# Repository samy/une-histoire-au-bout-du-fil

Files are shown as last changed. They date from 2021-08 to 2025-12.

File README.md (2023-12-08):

# Une histoire au bout du fil

Ce projet a pour objectif principal de convertir de vieux téléphones en boîte à histoires ou livres d'or!
<table width="100%" align="center">
    <tr>
      <td width="33%" valign="top" align="center"><a href="https://github.com/samy/une-histoire-au-bout-du-fil/tree/main/Boite_a_histoires/README.md"><strong>Boîte à histoires</strong><br />
        </a>
      </td>
      <td width="33%" valign="top" align="center"><a href="https://github.com/samy/une-histoire-au-bout-du-fil/tree/main/Livre_dor/README.md"><strong>Livre d'or</strong><br /></a></td>
  </tr>
</table>

Pour me contacter : samy@rabih.fr

# Licence
<br />Ce projet est partagé sous la licence <a rel="license" href="https://creativecommons.org/licenses/by-nc-sa/4.0/deed.fr">Attribution - Pas d’Utilisation Commerciale - Partage dans les Mêmes Conditions 4.0 International</a>.

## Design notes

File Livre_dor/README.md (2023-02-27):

## Notes
- Pour récupérer le son injecté dans le jack 3.5mm, on peut se brancher sur les PINs L et R (ceux sous le connecteur jack justement, R et GND sont reliés)

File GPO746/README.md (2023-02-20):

# GPO 746

Ce téléphone provient de Grande-Bretagne (et cet exemplaire date de 1968)


## Adaptation au boitier générique "Une histoire au bout du fil"

Afin de simplifier la conversion de mes téléphones, j'avais créé un boitier générique, avec 4 connecteurs A, B, C et D reliés aux 4 fils du cadran.
Mais cela fonctionnait avec un cadran français, et pas britannique comme celui-ci (le code couleur est différent).

| PIN PCB | Couleur fil UK |
| --- | --- |
| A | Bleu  |
| B | Orange  |
| C | Brun clair (ou rose)  |
| D | Gris  |

## Détection décrochage
Il faudra se brancher sur les connecteurs T1 et T19 du circuit du téléphone (et à défaut, sur T1 et T4)

## Pieds
La hauteur sous l'appareil étant insuffisante pour glisser le lecteur de carte microSD, il est nécessaire d'imprimer des cylindres de **16mm** de diamètre et d'au moins **6mm** de haut.

## Combiné
Un bruit de fond peut survenir dans le combiné, il suffit de rajouter une résistance de 4.7kΩ (pour un volume de 10). Si nécessaire monter jusqu'à 10kΩ (pour un volume de 15).

## Lecteur microSD
Si la SD n'est pas reconnue (erreur Time Out du DFPlayer), enlever (à la pince) la résistance située dans le lecteur SD

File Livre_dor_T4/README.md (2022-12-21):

## Notes
- Pour récupérer le son injecté dans le jack 3.5mm, on peut se brancher sur les PINs L et R (ceux sous le connecter jack justement, R et GND sont reliés)

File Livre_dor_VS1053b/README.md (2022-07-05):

## Correspondance des pins XIAO - VS1053

| VS1053 | XIAO |
| --- | --- |
| CS  | D7  |
| MISO  | D9  |
| (MO)SI  | D10  |
| SCK | D8  |
| XCS | D6  |
| XRESET | D5  |
| XDCS | D4  |
| DREQ | D3  |

Seul l'emplacement des MISO, MOSI et SCK est réellement important (pour les autres il vous suffit de changer les valeurs dans le code).
Correction dans la bibliothèque Adafruit VS1053

#define VS1053_CONTROL_SPI_SETTING                                             \
  SPISettings(2000000, MSBFIRST, SPI_MODE0) //!< VS1053 SPI control settings
#define VS1053_DATA_SPI_SETTING                                                \
  SPISettings(12000000, MSBFIRST, SPI_MODE0) //!< VS1053 SPI data settings
  
A rajouter dans le code Arduino:

#define SPI_HAS_TRANSACTION 1

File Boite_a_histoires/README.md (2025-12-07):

# Boite à histoires "Socotel U43"

Ce modèle date de 1943 (d'où son nom).

WhatsApp Image 2022-01-11 at 14 30 25 (1)

*Photo par [Lulu La Lucette](https://lululalucette.com)*

# Pré-requis
Sur la carte micro-SD ou la clé USB, créez un dossier nommé *MP3* et stockez-y vos fichiers à faire jouer par le téléphone.
Ils doivent être prefixés par un numéro à 4 chiffres, qui les fera correspondre au chiffre composé sur le cadran : 0001.mp3 ou 0001 - cequevousvoulez.mp3 pour le morceau 1, etc)

# Utilisation
Il vous suffit de décrocher le combiné, de composer un ou plusieurs chiffres et d'écouter l'histoire qui vous est racontée.

# Principe de fonctionnement
On reprend ici la logique du modèle S63 https://github.com/samy/une-histoire-au-bout-du-fil/blob/main/Boite_a_histoires_S63/README.md

Le boitier électronique associé à ce projet vient se brancher sur la connectique existante du téléphone, pour se relier à trois éléments déja présents:
- la détection du décrochage
- le combiné (et son haut-parleur)
- et surtout le cadran rotatif

Deux différences majeures par rapport à la version S63:
- le boitier a du être réduit en hauteur, l'espace disponible étant plus réduit
- afin d'éviter d'être parasité par le circuit du téléphone, on rajoute ici un sucre "maison" pour relier le cadran et l'Arduino

Il est désormais possible de composer des numéros entrre 1 et 4 chiffres !

# Schéma du circuit

<p>
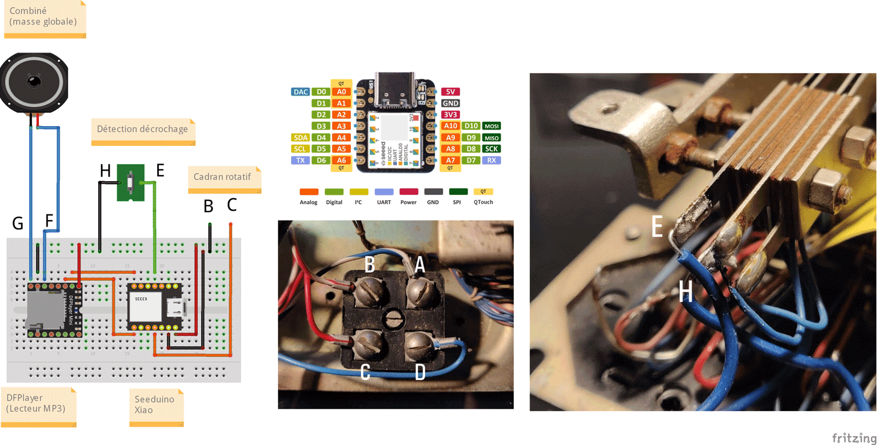
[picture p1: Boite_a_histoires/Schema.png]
  
</p>

Comme mon précédent modèle de téléphone, on utilise ici un DFPlayer, mais combiné cette fois à un [Seeeduino Xiao](https://wiki.seeedstudio.com/Seeeduino-XIAO/) qui a l'avantage d'être extrèmement compact (sans pour autant sacrifier les performances).

La seule particularité ici est que le décrochage n'a pu être géré directement par les bornes situées sous l'appareil : en effet, comme pour le cadran, les parasites liés au circuit sont trop importants. J'ai donc du directement me brancher sur les contacts du système électromécanique qui s'enclenche quand on raccroche.

# Gestion du volume (optionnelle)
Celle-ci peut s'activer via la constante VOLUME_HANDLING dans le code.
Il vous suffit ensuite de cabler un potentiomètre en reprenant la convention suivante:

potentiometre

# Compatibilité avec d'autres cadrans
Si vous avez un autre modèle qu'un Socotel S63 ou un U43, les cablâges sont sans doute tout de même similaires à l'image ci-dessous. Seuls les cables rouge et blanc-rouge sont utiles dans notre cas.



# Licence
<br />Ce projet est partagé sous la licence <a rel="license" href="https://creativecommons.org/licenses/by-nc-sa/4.0/deed.fr">Attribution - Pas d’Utilisation Commerciale - Partage dans les Mêmes Conditions 4.0 International</a>.

# Ressources:
- Autre projet, réalisé par [comeetie](https://github.com/comeetie/), qui utilise un U43, mais directement avec un Raspberry Pi: [https://github.com/comeetie/Monvieuxtelephone/](https://github.com/comeetie/Monvieuxtelephone/) (et qui ajoute pas mal de fonctionnalités: météo, horaires de passage du RER, etc)
- Source d'inspiration: [Le projet S63 de Revolunet](https://github.com/revolunet/s63)

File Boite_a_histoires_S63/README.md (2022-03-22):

# Boite à histoires "Socotel S63"



(source : [x0r.fr](https://x0r.fr/blog/53) )

## Schema du circuit


<table border="0" cellspacing="0" cellpadding="0">
  <tr>
    <td width="50%"></td>
    <td></td>
  </tr>
</table>

## Liaison cadran - Arduino

| Couleur | Destination |
| --- | --- |
| Blanc-bleu | Port A |
| Blanc-rouge | Port B |
| Rouge | Port C |
| Bleu | Port D |

# Matériel à rassembler
- Un [Arduino Nano](https://www.gotronic.fr/art-carte-arduino-nano-12422.htm) (mais vous pouvez utiliser d'autres modèles sans problème, selon votre boitier)
- Un [DFPlayer Mini](https://www.gotronic.fr/art-module-mp3-dfr0299-22404.htm)
- Une résistance de 1kΩ

# Pré-requis avant utilisation
Sur la carte micro-SD, créez un dossier nommé _MP3_ et stockez-y vos fichiers à faire jouer par le téléphone. Ils doivent être prefixés par un numéro à 4 chiffres, qui les fera correspondre au chiffre composé sur le cadran :
- **0001.mp3** ou **0001 - cequevousvoulez.mp3** pour le morceau 1,
- **0002.mp3** ou **0002 - cequevousvoulez.mp3** pour le morceau 2,
- etc

# Code Arduino
On utilise ici deux bibliothèques non natives :
- [*DFRobotDFPlayerMini*](https://github.com/DFRobot/DFRobotDFPlayerMini) (installable via le gestionnaire de bibliothèques)
- [*RotaryDial*](https://github.com/markfickett/Rotary-Dial), (téléchargeable sur Github et installable au format ZIP)

Le [code source](./Boite_a_histoires_S63.ino) est abondamment commenté en français.

# Etiquette du cadran
Celle-ci est constituée d'un disque de 51mm de diamètre, et la police utilisée semble être du Univers Condensed Medium avec en 7.5pt un crénage de 46 (merci à [Jean-François Porchez](https://typofonderie.com) pour la suggestion de la police Univers)



# Licence
<br />Ce projet est partagé sous la licence <a rel="license" href="https://creativecommons.org/licenses/by-nc-sa/4.0/deed.fr">Attribution - Pas d’Utilisation Commerciale - Partage dans les Mêmes Conditions 4.0 International</a>.

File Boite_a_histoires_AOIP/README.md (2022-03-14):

# Une histoire au bout du fil

Ce projet a pour objectif principal de convertir ce vieux téléphone (de la marque AOIP) en boîte à histoires!
telephone

# Technologie

L'idée principale qui sous-tend ce projet est de ne pas dénaturer le téléphone d'origine : on réutilisera donc la circuiterie d'origine, qui est en bon état.

Comme beaucoup de projets embarqués c'est ici un Arduino (Nano) qui sera employé.

Qui dit histoires dit "son" : en effet, on va devoir jouer des fichiers audio à travers le combiné (d'origine).

Cette tâche va être confiée à un lecteur [DFPlayer Mini](https://wiki.dfrobot.com/DFPlayer_Mini_SKU_DFR0299) (de la marque DFRobot)

En résumé vous aurez besoin de:
- Arduino Nano (officiel ou non)
- un DFPlayer Mini (autour de 5€)
- une carte micro-SD
- câbles Dupont ou de fils électriques classiques
- une [breadboard](https://www.robot-maker.com/ouvrages/2-1-utiliser-breadboard/) (carte de prototypage) pour pouvoir brancher les composants et les fils et facilement les replacer
- *ou* une [version à souder](https://www.amazon.fr/prototypage-Breadboard-Protoboard-Prototype-%C3%A9lectroniques/dp/B08F2TB5Y5/)

# Licence
<br />Ce projet est partagé sous la licence <a rel="license" href="https://creativecommons.org/licenses/by-nc-sa/4.0/deed.fr">Attribution - Pas d’Utilisation Commerciale - Partage dans les Mêmes Conditions 4.0 International</a>.

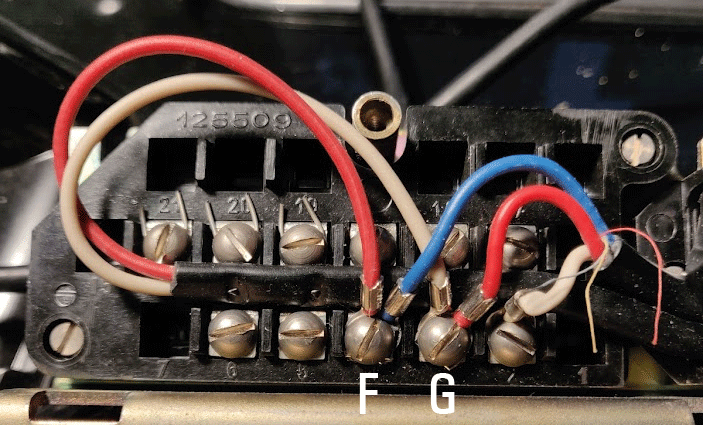
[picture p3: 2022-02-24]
Boite_a_histoires/Ressources/Platine_basse.png

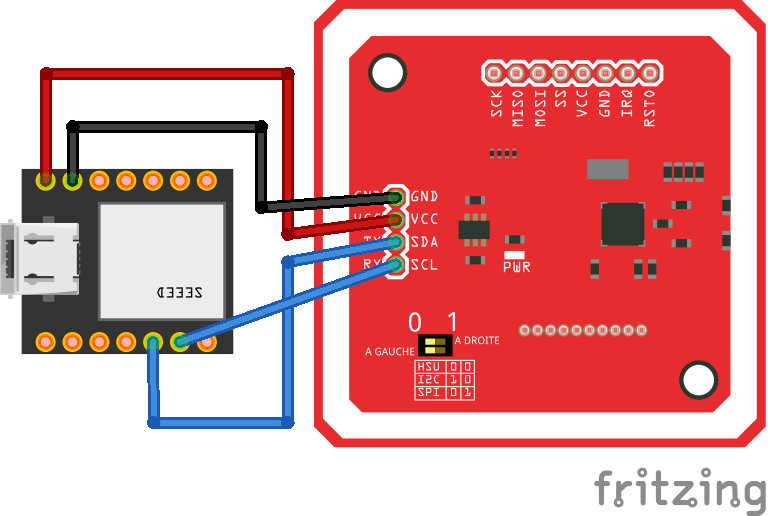
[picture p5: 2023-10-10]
Stethoscope/PN532.png

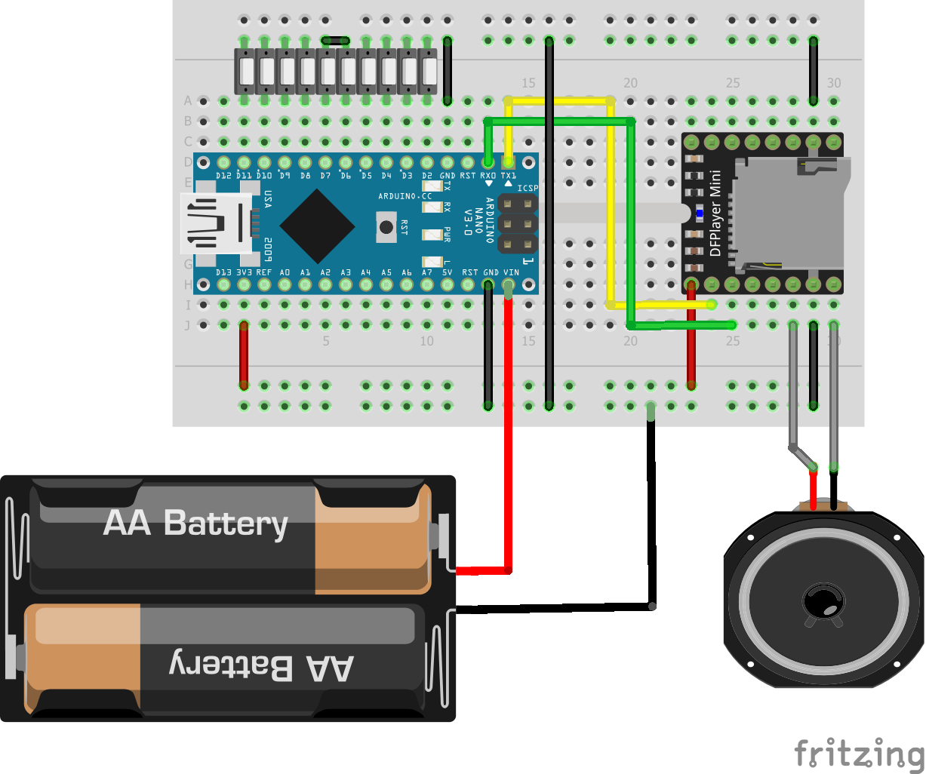
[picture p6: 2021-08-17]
Boite_a_histoires_AOIP/Schema.png

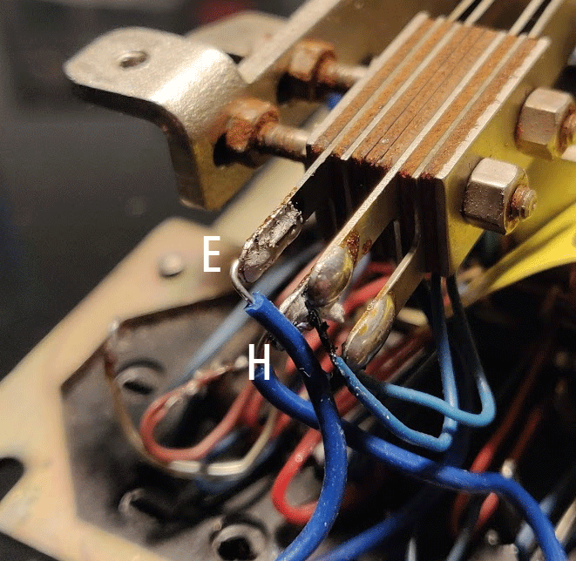
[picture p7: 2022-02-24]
Boite_a_histoires/Ressources/Contacts_decrochage.png

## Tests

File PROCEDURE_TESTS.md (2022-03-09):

# Procédure de tests
Celle-ci est commune à tous les modèles

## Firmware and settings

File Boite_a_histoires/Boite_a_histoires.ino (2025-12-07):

/* Bibliothèques requises */
#include <Bounce2.h>
#include "RotaryDial2.h"
#include <Keypad_MC17.h>
#include <Wire.h>
#include <Keypad.h>
#include "DFRobotDFPlayerMini.h" /* Lecteur MP3 */
#include <LibPrintf.h>


// Fonctionnalités
#define INTRO_ENABLE false /* Pour activer le message au décrochage  */
#define INTRO_DELTA 1      /* Temps minimal en secondes entre deux diffusions du message de décrochage */

#define DIALER_ENABLE true               /* Pour activer le clavier */
#define DIAL_RANDOM false                  /* Si le cadran doit lire au hasard */
#define DIALER_TYPE DIALER_TYPE_ROTARY    /* Type : DIALER_TYPE_KEYPAD clavier à touches, DIALER_TYPE_ROTARY cadran rotatif */
#define DIALER_COUNTRY "FR"               /* FR pour cadrans français, UK pour britanniques */
#define DIALED_NUMBERS_MAX 1              /* Nombre maximal de numéros (1 : 10 chiffres, 2 : 100 chiffres, etc) */
#define STORAGE_DEVICE DFPLAYER_DEVICE_SD /* Support de stockage: DFPLAYER_DEVICE_SD pour SD, DFPLAYER_DEVICE_U_DISK pour clé USB */
#define LED_ENABLE false                  /* Activation de la LED d'indication de fonctionnement */
#define LED_PIN D9                        /* Gestion de la LED */
#define USE_BOUNCE_INSTEAD_OF_DIRECT 0    /* Pour des systèmes de raccrochage un peu sensibles */

#define KEYPAD_REVERSED_MATRIX true

#define RANDOM_PLAY_ON_HANG false              /* Activation du mode Lecture automatique et aléatoire au décrochage de l'appareil */
#define RANDOM_PLAY_ON_HANG_START_ON_TRACK -1 /* En mode aléatoire, le numéro du morceau joué au démarrage */
#define USE_SOFTWARE_RANDOM false             /* Lecture aléatoire en se basant sur le nombre de fichiers, dans le cas ou randomAll() marche mal */


#define VOLUME_HANDLING false /* Activation de la molette de volume branchée sur le PIN A1 */
#define MAX_VOLUME 10         /* Volume maximal quand la molette est au maximum */

#define HANG_REVERSE true /* Inversion du raccrochage, selon les appareils */

// Gestion bouton supplémentaire
#define EXTRA_HANG false        /* Activation du bouton secondaire pour le raccrochage */
#define EXTRA_HANG_PIN A2       /* PIN du bouton supplémentaire de raccrochage */
#define EXTRA_HANG_REVERSE true /* Si le fonctionnement de ce bouton supplémentaire est inversé */

// Inclusion des valeurs par défaut pour celles qui n'ont pas été personnalisées ci-dessus
#include "Variables.h"

Keypad_MC17 keypad(makeKeymap(keys), rowPins, colPins, ROWS, COLS, I2CADDR);

// "Bouton" utilisé pour gérer le décrochage
Bounce2::Button button = Bounce2::Button();

void setup() {
  delay(3000);

  pinMode(PIN_HANG, INPUT_PULLUP);
  button.attach(PIN_HANG, INPUT_PULLUP);
  button.interval(5);
  button.setPressedState(HANG_REVERSE ? 1 : 0);

  /* Optionnel: Gestion du volume */
  if (VOLUME_HANDLING) {
    pinMode(A1, INPUT);
  }

  /* Optionnel: LED d'indication de fonctionnement */
  if (LED_ENABLE) {
    pinMode(LED_PIN, OUTPUT);
    digitalWrite(LED_PIN, HIGH);
  }

  /* Optionnel: 2e dispositif de raccrochage */
  if (EXTRA_HANG) {
    pinMode(EXTRA_HANG_PIN, INPUT_PULLUP);
  }

  /* Connexion série pour la remontée d'informations au PC */
  Serial.begin(9600);

  /* Connexion série pour la communication avec le DFPlayer */
  mySoftwareSerial.begin(9600);

  /* Gestion du clavier */
  if (DIALER_ENABLE) {
    /* Clavier à touches */
    if (DIALER_TYPE == DIALER_TYPE_KEYPAD) {
      Wire.begin();  // now needed
      keypad.begin();
    } else {
      /* Cadran rotatif */
      RotaryDial2::setup(PIN_PULSE, DIALED_NUMBERS_MAX);
    }
  }

  /* Connexion au DFPlayer */
  if (!myDFPlayer.begin(mySoftwareSerial, true, true)) {  //Use softwareSerial to communicate with mp3.
    Serial.println("bad");
    return;
  }
  Serial.println("Starting successfully");

  myDFPlayer.outputDevice(STORAGE_DEVICE);
  myDFPlayer.pause();

  delay(3000);
  audioFilesCount = myDFPlayer.readFileCounts(DFPLAYER_DEVICE_SD);
  Serial.print("Audio files count");
  Serial.println(audioFilesCount);
  myDFPlayer.volume(20);
  printSettingsToConsole();
}

void loop() {
  /* Optionnel: Actualisation du volume */
  if (VOLUME_HANDLING) {
    int volume = getVolume();

    if (lastVolume == -1 || abs(lastVolume - volume) > 30) {
      lastVolume = volume;

      Serial.println(map(volume, 0, 1023, 0, MAX_VOLUME));
      delay(200);
      myDFPlayer.volume(map(volume, 0, 1023, 0, MAX_VOLUME));
      delay(100);
    }
  }
  if (myDFPlayer.available()) {
    printDetail(myDFPlayer.readType(), myDFPlayer.read());  //Print the detail message from DFPlayer to handle different errors and states.
  }
  button.update();



  /* Si le téléphone est raccroché, on stoppe la lecture du MP3 (il n'a pas de véritable stop() et on passe à l'itération suivante */
  if (isHangedUp() || (EXTRA_HANG && isExtraHangedUp())) {

    Serial.println("Offline");
    delay(200);
    if (phoneStatus != 0) {
      myDFPlayer.pause();
    }

    phoneStatus = 0;
    dialedIndex = 0;
    return;
  } else {
    if (phoneStatus == 0) {
      myDFPlayer.available();

      delay(300);
      /* Si l'option de lecture aléatoire au décrochage est activée, on joue un audio au hasard
      le changement de phoneStatus évite qu'il soit joué plusieurs fois */
      if (RANDOM_PLAY_ON_HANG) {
        if (RANDOM_PLAY_ON_HANG_START_ON_TRACK != -1) {
          Serial.print("Play on start: track ");
          Serial.println(RANDOM_PLAY_ON_HANG_START_ON_TRACK);
          myDFPlayer.play(RANDOM_PLAY_ON_HANG_START_ON_TRACK);
        } else {
          if (!USE_SOFTWARE_RANDOM) {
            Serial.println("Random play on start");

            myDFPlayer.randomAll();
          } else {
            int randomFileNumber = random(1, audioFilesCount);
            Serial.print("Random play (software) on start:");
            Serial.println(randomFileNumber);

            myDFPlayer.play(randomFileNumber);
          }
        }
      } else {
        Serial.println("No random");
      }
      dialedIndex = 0;
      phoneStatus = 1;
    }
  }

  if (timeSinceLastIntroPlay == 99999 || (phoneStatus == 1 && needToPlayIntro())) {
    Serial.println("needToPlayIntro?");
    phoneStatus = 2;
    playIntro();
  }
  phoneStatus = 2;
  if (DIALER_ENABLE) {
    if (DIALER_TYPE == DIALER_TYPE_KEYPAD) {
      char key = keypad.getKey();
      if (key) {
        numberDialed = convertKeypadToInt(key);
      }
    } else {
      /* Si un numéro a été composé sur le téléphone, on le stocke */
      if (strcmp(DIALER_COUNTRY, "FR") == 0) {
        if (RotaryDial2::available()) {

          delay(200);

          numberDialed = RotaryDial2::read();
        }
      }
      if (strcmp(DIALER_COUNTRY, "UK") == 0) {
        numberDialed = getUkRotaryDialerNumber();
      }
    }

    /* Si un numéro a été composé, alors on joue le MP3 correspondant */
    if (numberDialed != -1) {
      dialedIndex++;

      /* Stockage des numéros composés */
      if (dialedIndex <= DIALED_NUMBERS_MAX) {
        dialedNumbers[dialedIndex - 1] = numberDialed;
        numberDialed = -1;
        if (dialedIndex < DIALED_NUMBERS_MAX) {
          return;
        }
      }
      if (dialedIndex > DIALED_NUMBERS_MAX) {
        dialedIndex = 0;
        numberDialed = -1;
        return;
      }
      for (int i = 0; i < dialedIndex; i++) {
        finalDialedNumber += pow(10, DIALED_NUMBERS_MAX - 1 - i) * dialedNumbers[i];
        dialedNumbers[i] = 0;
      }
      dialedIndex = 0;
      myDFPlayer.pause();
      if (DIAL_RANDOM) {
        finalDialedNumber = random(1, audioFilesCount + 1);
        myDFPlayer.available();
        delay(300);
        Serial.print("randomDialedNumber=");
        Serial.println(finalDialedNumber);
        myDFPlayer.randomAll();
      } else {
        Serial.print("finalDialedNumber=");
        Serial.println(finalDialedNumber);
        myDFPlayer.playMp3Folder(finalDialedNumber);
      }

      numberDialed = -1;
      finalDialedNumber = 0;
      return;
    }
  } else {
    /* Si le lecteur n'est pas actuellement en train de jouer */
    if (myDFPlayer.readState() == 514 || myDFPlayer.readState() == 512) {
      delay(1000);

      myDFPlayer.randomAll();
    }
    delay(1000);
  }
}

/* Récupération de l'état de décroché/raccroché */
bool isHangedUp() {
  if (USE_BOUNCE_INSTEAD_OF_DIRECT) {
    return button.pressed();
  }
  return (HANG_REVERSE ? 0 : 1) == digitalRead(PIN_HANG);
}
/* Récupération de l'état de décroché/raccroché */
bool isExtraHangedUp() {
  return (EXTRA_HANG_REVERSE ? 0 : 1) == digitalRead(EXTRA_HANG_PIN);
}

/* Détermination de la nécessité de jouer le message d'intro */
bool needToPlayIntro() {
  if (!INTRO_ENABLE) {
    return false;
  }
  /* Si l'écart entre le compteur de temps actuel et la dernière lecture de l'introduction dépasse l'intervalle qu'on a configuré,
    et que le téléphone était décroché avant
    on joue l'intro */
  if (timeSinceLastIntroPlay == 0 || (millis() - timeSinceLastIntroPlay) > INTRO_DELTA * 1000) {
    return true;
  }
  return false;
}

/* Diffusion du message d'introduction */
void playIntro() {
  timeSinceLastIntroPlay = millis();

  delay(1000);                 /* On laisse aux utilisateurs le temps de décrocher */
  myDFPlayer.playMp3Folder(0); /* L'intro est stockée dans le fichier commençant par 0000 dans le dossier MP3 */
}

int getUkRotaryDialerNumber() {
  int reading = digitalRead(PIN_PULSE);
  int numberDialed = -1;
  if ((millis() - lastStateChangeTime) > dialHasFinishedRotatingAfterMs) {
    if (needToPrint) {
      // if it's only just finished being dialed, we need to send the number down the serial
      // line and reset the count. We mod the count by 10 because '0' will send 10 pulses.
      numberDialed = count % 10;
      needToPrint = 0;
      count = 0;
      cleared = 0;
    }
  }

  if (reading != lastState) {
    lastStateChangeTime = millis();
  }
  if ((millis() - lastStateChangeTime) > debounceDelay) {
    // debounce - this happens once it's stablized
    if (reading != trueState) {
      // this means that the switch has either just gone from closed->open or vice versa.
      trueState = reading;
      if (trueState == HIGH) {
        // increment the count of pulses if it's gone high.
        count++;
        needToPrint = 1;  // we'll need to print this number (once the dial has finished rotating)
      }
    }
  }
  lastState = reading;
  return numberDialed;
}

long getVolume() {
  return analogRead(A1);
}
int convertKeypadToInt(char key) {
  return key - '0';
}

void printDetail(uint8_t type, int value) {
  switch (type) {
    case TimeOut:
      Serial.println(F("Time Out!"));
      break;
    case WrongStack:
      Serial.println(F("Stack Wrong!"));
      break;
    case DFPlayerCardInserted:
      Serial.println(F("Card Inserted!"));
      break;
    case DFPlayerCardRemoved:
      Serial.println(F("Card Removed!"));
      break;
    case DFPlayerCardOnline:
      Serial.println(F("Card Online!"));
      break;
    case DFPlayerPlayFinished:
      Serial.print(F("Number:"));
      Serial.print(value);
      Serial.println(F(" Play Finished!"));
      break;
    case DFPlayerError:
      Serial.print(F("DFPlayerError:"));
      switch (value) {
        case Busy:
          Serial.println(F("Card not found"));
          break;
        case Sleeping:
          Serial.println(F("Sleeping"));
          break;
        case SerialWrongStack:
          Serial.println(F("Get Wrong Stack"));
          break;
        case CheckSumNotMatch:
          Serial.println(F("Check Sum Not Match"));
          break;
        case FileIndexOut:
          Serial.println(F("File Index Out of Bound"));
          break;
        case FileMismatch:
          Serial.println(F("Cannot Find File"));
          break;
        case Advertise:
          Serial.println(F("In Advertise"));
          break;
        default:
          break;
      }
      break;
    default:
      break;
  }
}

const char* boolToEnabled(int value) {
  return value ? "enabled" : "disabled";
}

void printSettingsToConsole() {
  Serial.println();
  Serial.println("# Settings summary");
  printf("* Intro : %s\n", boolToEnabled(INTRO_ENABLE));
  if (INTRO_ENABLE) {
    printf("  * Delay after intro plays a new time : %d seconds\n", INTRO_DELTA);
  }
  printf("* Reversed hang : %s\n", boolToEnabled(HANG_REVERSE));

  printf("* Dialer : %s\n", boolToEnabled(DIALER_ENABLE));
  if (DIALER_ENABLE) {
    if (DIAL_RANDOM) {
      printf("  * Random mode: %s\n", boolToEnabled(DIAL_RANDOM));
    } else {
      printf("  * Max numbers: %d\n", int(pow(10, DIALED_NUMBERS_MAX)));
    }
    printf("  * Type: %s\n", DIALER_TYPE);
    if (DIALER_TYPE == DIALER_TYPE_KEYPAD) {
      printf("  * Matrix reversed: %s\n", boolToEnabled(KEYPAD_REVERSED_MATRIX));
    }
    printf("  * Country: %s\n", DIALER_COUNTRY);
  }
  printf("* Storage type : %s\n", STORAGE_DEVICE == DFPLAYER_DEVICE_U_DISK ? "USB" : "SD");
  printf("* LED : %s\n", boolToEnabled(LED_ENABLE));
  if (LED_ENABLE) {
    printf("  * LED pin: %s\n", LED_PIN);
  }
  printf("* Volume handling : %s\n", boolToEnabled(VOLUME_HANDLING));
  if (VOLUME_HANDLING) {
    printf("  * Max volume: %d\n", MAX_VOLUME);
  }
  printf("* Use software random : %s\n", boolToEnabled(USE_SOFTWARE_RANDOM));
  printf("* Random play on hang : %s\n", boolToEnabled(RANDOM_PLAY_ON_HANG));
  if (RANDOM_PLAY_ON_HANG && -1 != RANDOM_PLAY_ON_HANG_START_ON_TRACK) {
    printf("  * First track on hang: %d\n", RANDOM_PLAY_ON_HANG_START_ON_TRACK);
  }
  if (EXTRA_HANG) {
    printf("* Use extra hang switch : %s\n", boolToEnabled(EXTRA_HANG));
    printf("  * Pin: %s\n", EXTRA_HANG_PIN);
    printf("  * Reversed: %s\n", boolToEnabled(EXTRA_HANG_REVERSE));
  }

  //Extra settings
  if (USE_BOUNCE_INSTEAD_OF_DIRECT) {
    printf("* Use bounce instead of direct switch handling : %s\n", boolToEnabled(USE_BOUNCE_INSTEAD_OF_DIRECT));
  }


  Serial.println();
}

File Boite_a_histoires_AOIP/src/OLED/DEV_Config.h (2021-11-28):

/******************************************************************************
**************************Hardware interface layer*****************************
  | file      	:	DEV_Config.h
  |	version		:	V1.0
  | date		:	2017-12-11
  | function	:
	Provide the hardware underlying interface
******************************************************************************/
#ifndef _DEV_CONFIG_H_
#define _DEV_CONFIG_H_

#include <SPI.h>
#include <Wire.h>

#define USE_SPI_4W 1
#define USE_IIC    0

#define IIC_CMD        0X00
#define IIC_RAM        0X40
/****************************************************************************************
		//Use the  library function definition
*****************************************************************************************/
//GPIO config
//OLED
#define OLED_CS A3
#define OLED_DC A2
#define OLED_CS_0	    digitalWrite(OLED_CS, LOW)
#define OLED_CS_1		digitalWrite(OLED_CS, HIGH)

#ifndef OLED_RST
#define OLED_RST 8
#endif
#define OLED_RST_0		digitalWrite(OLED_RST, LOW)
#define OLED_RST_1		digitalWrite(OLED_RST, HIGH)


#define OLED_DC_0		digitalWrite(OLED_DC, LOW)
#define OLED_DC_1	  	digitalWrite(OLED_DC, HIGH)

#define SPIRAM_CS 5
#define SPIRAM_CS_0     digitalWrite(SPIRAM_CS, LOW)
#define SPIRAM_CS_1     digitalWrite(SPIRAM_CS, HIGH)

/*------------------------------------------------------------------------------------------------------*/
uint8_t System_Init(void);

void SPI4W_Write_Byte(uint8_t DATA);
uint8_t SPI4W_Read_Byte(uint8_t DATA);

void I2C_Write_Byte(uint8_t value, uint8_t Cmd);

void Driver_Delay_ms(unsigned long xms);
void Driver_Delay_us(int xus);

#endif

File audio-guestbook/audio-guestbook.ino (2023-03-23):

/**
 * Audio Guestbook, Copyright (c) 2022 Playful Technology
 * 
 * Tested using a Teensy 4.0 with Teensy Audio Shield, although should work 
 * with minor modifications on other similar hardware
 * 
 * When handset is lifted, a pre-recorded greeting message is played, followed by a tone.
 * Then, recording starts, and continues until the handset is replaced.
 * Playback button allows all messages currently saved on SD card through earpiece 
 * 
 * Files are saved on SD card as 44.1kHz, 16-bit, mono signed integer RAW audio format 
 * --> changed this to WAV recording, DD4WH 2022_07_31
 * 
 * 
 * Frank DD4WH, August 1st 2022 
 * for a DBP 611 telephone (closed contact when handheld is lifted) & with recording to WAV file
 * contact for switch button 0 is closed when handheld is lifted
 * 
 * GNU GPL v3.0 license
 * 
 */



#include <Bounce.h>
#include <Audio.h>
#include <Wire.h>
#include <SPI.h>
#include <SD.h>
#include <TimeLib.h>
#include "play_sd_wav.h"  // local copy with fixes

// DEFINES
// Define pins used by Teensy Audio Shield
#define SDCARD_CS_PIN 10
#define SDCARD_MOSI_PIN 7
#define SDCARD_SCK_PIN 14
// And those used for inputs
#define HOOK_PIN 0
#define PLAYBACK_BUTTON_PIN 4

#define noINSTRUMENT_SD_WRITE

// GLOBALS
// Audio initialisation code can be generated using the GUI interface at https://www.pjrc.com/teensy/gui/
// Inputs
AudioSynthWaveform waveform1;                        // To create the "beep" sfx
AudioInputI2S i2s2;                                  // I2S input from microphone on audio shield
AudioPlaySdWavX playWav1;                            // Play 44.1kHz 16-bit PCM greeting WAV file
AudioRecordQueue queue1;                             // Creating an audio buffer in memory before saving to SD
AudioMixer4 mixer;                                   // Allows merging several inputs to same output
AudioOutputI2S i2s1;                                 // I2S interface to Speaker/Line Out on Audio shield
AudioConnection patchCord1(waveform1, 0, mixer, 0);  // wave to mixer
AudioConnection patchCord3(playWav1, 0, mixer, 1);   // wav file playback mixer
AudioConnection patchCord4(mixer, 0, i2s1, 0);       // mixer output to speaker (L)
AudioConnection patchCord6(mixer, 0, i2s1, 1);       // mixer output to speaker (R)
AudioConnection patchCord5(i2s2, 0, queue1, 0);      // mic input to queue (L)
AudioControlSGTL5000 sgtl5000_1;

// Filename to save audio recording on SD card
char filename[15];
// The file object itself
File frec;

// Use long 40ms debounce time on both switches
Bounce buttonRecord = Bounce(HOOK_PIN, 40);
Bounce buttonPlay = Bounce(PLAYBACK_BUTTON_PIN, 40);

// Keep track of current state of the device
enum Mode { Initialising,
            Ready,
            Prompting,
            Recording,
            Playing };
Mode mode = Mode::Initialising;

float beep_volume = 0.02f;  // not too loud :-)


// variables for writing to WAV file
unsigned long ChunkSize = 0L;
unsigned long Subchunk1Size = 16;
unsigned int AudioFormat = 1;
unsigned int numChannels = 1;
unsigned long sampleRate = 44100;
unsigned int bitsPerSample = 16;
unsigned long byteRate = sampleRate * numChannels * (bitsPerSample / 8);  // samplerate x channels x (bitspersample / 8)
unsigned int blockAlign = numChannels * bitsPerSample / 8;
unsigned long Subchunk2Size = 0L;
unsigned long recByteSaved = 0L;
unsigned long NumSamples = 0L;
byte byte1, byte2, byte3, byte4;


void setup() {

  Serial.begin(9600);
  while (!Serial && millis() < 5000) {
    // wait for serial port to connect.
  }
  Serial.println("Serial set up correctly");
  Serial.printf("Audio block set to %d samples\n", AUDIO_BLOCK_SAMPLES);
  print_mode();
  // Configure the input pins
  pinMode(HOOK_PIN, INPUT_PULLUP);
  pinMode(PLAYBACK_BUTTON_PIN, INPUT_PULLUP);

  // Audio connections require memory, and the record queue
  // uses this memory to buffer incoming audio.
  AudioMemory(60);

  // Enable the audio shield, select input, and enable output
  sgtl5000_1.enable();
  // Define which input on the audio shield to use (AUDIO_INPUT_LINEIN / AUDIO_INPUT_MIC)
  sgtl5000_1.inputSelect(AUDIO_INPUT_MIC);
  //sgtl5000_1.adcHighPassFilterDisable(); //
  sgtl5000_1.volume(0.95);
  sgtl5000_1.adcHighPassFilterEnable();
  sgtl5000_1.unmuteLineout();
  mixer.gain(0, 5.0f);
  mixer.gain(1, 5.0f);

  // Play a beep to indicate system is online
  waveform1.begin(beep_volume, 440, WAVEFORM_SINE);
  wait(1000);
  waveform1.amplitude(0);
  delay(1000);

  // Initialize the SD card
  SPI.setMOSI(SDCARD_MOSI_PIN);
  SPI.setSCK(SDCARD_SCK_PIN);
  if (!(SD.begin(SDCARD_CS_PIN))) {
    // stop here if no SD card, but print a message
    while (1) {
      Serial.println("Unable to access the SD card");
      delay(500);
    }
  } else Serial.println("SD card correctly initialized");


  // Value in dB
  //  sgtl5000_1.micGain(15);
  sgtl5000_1.micGain(5);  // much lower gain is required for the AOM5024 electret capsule

  // Synchronise the Time object used in the program code with the RTC time provider.
  // See https://github.com/PaulStoffregen/Time
  setSyncProvider(getTeensy3Time);

  // Define a callback that will assign the correct datetime for any file system operations
  // (i.e. saving a new audio recording onto the SD card)
  FsDateTime::setCallback(dateTime);

  mode = Mode::Ready;
  print_mode();
}
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

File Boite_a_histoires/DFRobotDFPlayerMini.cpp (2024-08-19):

/*!
 * @file DFRobotDFPlayerMini.cpp
 * @brief DFPlayer - An Arduino Mini MP3 Player From DFRobot
 * @n Header file for DFRobot's DFPlayer
 *
 * @copyright	[DFRobot]( http://www.dfrobot.com ), 2016
 * @copyright	GNU Lesser General Public License
 *
 * @author [Angelo](Angelo.qiao@dfrobot.com)
 * @version  V1.0.6
 * @date  2016-12-07
 */

#include "DFRobotDFPlayerMini.h"

void DFRobotDFPlayerMini::setTimeOut(unsigned long timeOutDuration) {
  _timeOutDuration = timeOutDuration;
}

void DFRobotDFPlayerMini::uint16ToArray(uint16_t value, uint8_t *array) {
  *array = (uint8_t)(value >> 8);
  *(array + 1) = (uint8_t)(value);
}

uint16_t DFRobotDFPlayerMini::calculateCheckSum(uint8_t *buffer) {
  uint16_t sum = 0;
  for (int i = Stack_Version; i < Stack_CheckSum; i++) {
    sum += buffer[i];
  }
  return -sum;
}

void DFRobotDFPlayerMini::sendStack() {
  if (_sending[Stack_ACK]) {  //if the ack mode is on wait until the last transmition
    while (_isSending) {
      delay(0);
      waitAvailable();
    }
  }

#ifdef _DEBUG
  Serial.println();
  Serial.print(F("sending:"));
  for (int i = 0; i < DFPLAYER_SEND_LENGTH; i++) {
    Serial.print(_sending[i], HEX);
    Serial.print(F(" "));
  }
  Serial.println();
#endif
  _serial->write(_sending, DFPLAYER_SEND_LENGTH);
  _timeOutTimer = millis();
  _isSending = _sending[Stack_ACK];

  if (!_sending[Stack_ACK]) {  //if the ack mode is off wait 10 ms after one transmition.
    delay(10);
  }
}

void DFRobotDFPlayerMini::sendStack(uint8_t command) {
  sendStack(command, 0);
}

void DFRobotDFPlayerMini::sendStack(uint8_t command, uint16_t argument) {
  _sending[Stack_Command] = command;
  uint16ToArray(argument, _sending + Stack_Parameter);
  uint16ToArray(calculateCheckSum(_sending), _sending + Stack_CheckSum);
  sendStack();
}

void DFRobotDFPlayerMini::sendStack(uint8_t command, uint8_t argumentHigh, uint8_t argumentLow) {
  uint16_t buffer = argumentHigh;
  buffer <<= 8;
  sendStack(command, buffer | argumentLow);
}

void DFRobotDFPlayerMini::enableACK() {
  _sending[Stack_ACK] = 0x01;
}

void DFRobotDFPlayerMini::disableACK() {
  _sending[Stack_ACK] = 0x00;
}

bool DFRobotDFPlayerMini::waitAvailable(unsigned long duration) {
  unsigned long timer = millis();
  if (!duration) {
    duration = _timeOutDuration;
  }
  while (!available()) {
    if (millis() - timer > duration) {
      return handleError(TimeOut);
    }
    delay(0);
  }
  return true;
}

bool DFRobotDFPlayerMini::begin(Stream &stream, bool isACK, bool doReset) {
  _serial = &stream;

  if (isACK) {
    enableACK();
  } else {
    disableACK();
  }

  if (doReset) {
    reset();
    waitAvailable(2000);
    delay(200);
  } else {
    // assume same state as with reset(): online
    _handleType = DFPlayerCardOnline;
  }

  return (readType() == DFPlayerCardOnline) || (readType() == DFPlayerUSBOnline) || !isACK;
}

uint8_t DFRobotDFPlayerMini::readType() {
  _isAvailable = false;
  return _handleType;
}

uint16_t DFRobotDFPlayerMini::read() {
  _isAvailable = false;
  return _handleParameter;
}

bool DFRobotDFPlayerMini::handleMessage(uint8_t type, uint16_t parameter) {
  _receivedIndex = 0;
  _handleType = type;
  _handleParameter = parameter;
  _isAvailable = true;
  return _isAvailable;
}

bool DFRobotDFPlayerMini::handleError(uint8_t type, uint16_t parameter) {
  handleMessage(type, parameter);
  _isSending = false;
  return false;
}

uint8_t DFRobotDFPlayerMini::readCommand() {
  _isAvailable = false;
  return _handleCommand;
}

void DFRobotDFPlayerMini::parseStack() {
  uint8_t handleCommand = *(_received + Stack_Command);
  if (handleCommand == 0x41) {  //handle the 0x41 ack feedback as a spcecial case, in case the pollusion of _handleCommand, _handleParameter, and _handleType.
    _isSending = false;
    return;
  }

  _handleCommand = handleCommand;
  _handleParameter = arrayToUint16(_received + Stack_Parameter);

  switch (_handleCommand) {
    case 0x3C:
    case 0x3D:
      handleMessage(DFPlayerPlayFinished, _handleParameter);
      break;
    case 0x3F:
      if (_handleParameter & 0x01) {
        handleMessage(DFPlayerUSBOnline, _handleParameter);
      } else if (_handleParameter & 0x02) {
        handleMessage(DFPlayerCardOnline, _handleParameter);
      } else if (_handleParameter & 0x03) {
        handleMessage(DFPlayerCardUSBOnline, _handleParameter);
      }
      break;
    case 0x3A:
      if (_handleParameter & 0x01) {
        handleMessage(DFPlayerUSBInserted, _handleParameter);
      } else if (_handleParameter & 0x02) {
        handleMessage(DFPlayerCardInserted, _handleParameter);
      }
      break;
    case 0x3B:
      if (_handleParameter & 0x01) {
        handleMessage(DFPlayerUSBRemoved, _handleParameter);
      } else if (_handleParameter & 0x02) {
        handleMessage(DFPlayerCardRemoved, _handleParameter);
      }
      break;
    case 0x40:
      handleMessage(DFPlayerError, _handleParameter);
      break;
    case 0x3E:
    case 0x42:
    case 0x43:
    case 0x44:
    case 0x45:
    case 0x46:
    case 0x47:
    case 0x48:
    case 0x49:
    case 0x4B:
    case 0x4C:
    case 0x4D:
    case 0x4E:
    case 0x4F:
      handleMessage(DFPlayerFeedBack, _handleParameter);
      break;
    default:
      handleError(WrongStack);
      break;
  }
}

uint16_t DFRobotDFPlayerMini::arrayToUint16(uint8_t *array) {
  uint16_t value = *array;
  value <<= 8;
  value += *(array + 1);
  return value;
}

bool DFRobotDFPlayerMini::validateStack() {
  return calculateCheckSum(_received) == arrayToUint16(_received + Stack_CheckSum);
}

bool DFRobotDFPlayerMini::available() {
  while (_serial->available()) {
    delay(0);
    if (_receivedIndex == 0) {
      _received[Stack_Header] = _serial->read();
#ifdef _DEBUG
      Serial.print(F("received:"));
      Serial.print(_received[_receivedIndex], HEX);
      Serial.print(F(" "));
#endif
      if (_received[Stack_Header] == 0x7E) {
        _receivedIndex++;
      }
    } else {
      _received[_receivedIndex] = _serial->read();
#ifdef _DEBUG
      Serial.print(_received[_receivedIndex], HEX);
      Serial.print(F(" "));
#endif
      switch (_receivedIndex) {
        case Stack_Version:
          if (_received[_receivedIndex] != 0xFF) {
            return handleError(WrongStack);
          }
          break;
        case Stack_Length:
          if (_received[_receivedIndex] != 0x06) {
            return handleError(WrongStack);
          }
          break;
        case Stack_End:
#ifdef _DEBUG
          Serial.println();
#endif
          if (_received[_receivedIndex] != 0xEF) {
            return handleError(WrongStack);
          } else {
            if (validateStack()) {
              _receivedIndex = 0;
              parseStack();
              return _isAvailable;
            } else {
              return handleError(WrongStack);
            }
          }
          break;
        default:
          break;
      }
      _receivedIndex++;
    }
  }


  return _isAvailable;
}
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

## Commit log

2021-08-07 Premier jet, on initialise juste les boutons
2021-08-14 Début gestion des boutons
2021-08-14 Gestion des boutons
2021-08-14 Correction ordre d'initialisation + renommage
    [Une_histoire_au_bout_du_fil.ino]
2021-09-20 Gestion de l'extinction / allumage
2021-10-20 On rend les variables de configuration OLED surchargeables
2021-11-29 Ajout de la gestion du décrochage
2021-11-30 Correction fonctionnement lecteur MP3
    [Boite_a_histoires_S63.ino]
2021-12-05 Ajout schéma breadboard
    [Schema.fz]
2021-12-05 Actualisation schémas
    [Schema.fz]
2022-01-13 Ajout schemas Nano et Xiao
    [Schema.fz, Schema_Arduino_Nano.fz, Schema_Seeduino_Xiao.fz]
2022-01-26 Ajout images correctes
    [Schema_Seeduino_Xiao.fz]
2022-01-26 Mise à jour de la documentation
2022-01-26 On isole la documentation du modèle AOIP à part
2022-01-26 Mise à jour des PSD
2022-01-26 Ajout du matériel nécessaire + bibliothèques Arduino
2022-01-30 Correction schéma suite feedback Jean-Charles Amey
    [Schema_Arduino_Nano.fz, Schema_Seeduino_Xiao.fz]
2022-01-30 play > playMp3Folder
    changement de play à playMp3Folder (ligne 55-56)
    + ajout d’un commentaire sur la structure de dossier et dommage des mp3
2022-01-30 Amélioration du README
    Rajout du prérequis pour indiquer l'étape de stockage des MP3 dans le bon dossier
2022-02-24 Ajout longueur des fils
2022-06-12 Ajout code random
    [Schema_Seeduino_Xiao.fz]
2022-08-31 Fix pour le mode aléatoire
    [Boite_random.ino]
2022-10-20 Mises à jour diverses
    [Schema_Seeduino_Xiao.fz]
2022-10-20 Corrections retours chariot
    [Schema_Arduino_Nano.fz, Schema_Seeduino_Xiao.fz]
2022-10-20 Ajout délai avant lecture de l'intro
2022-10-20 Correction retours chariot
    [Schema_Arduino_Nano.fz, Schema_Seeduino_Xiao.fz]
2022-12-15 Debug pour Teensy
2022-12-15 Debug Teensy
2023-01-02 Gestion de l'intro
2023-01-06 Integration de audioguestbook
2023-01-08 Gestion du replay + reset
    [Livre_dor.ino, phone_guestbook.cpp, phone_guestbook.h]
2023-02-20 Correction retour de ligne
2023-02-27 Ajout audio-gestbook
    [AudioGuestbook.fzz]
2023-04-13 Correction PINs pour le S63
    [Boite_a_histoires_S63.ino]
2023-06-24 Fix - Limitation de l'écriture sur la carte SD
    [Livre_dor.ino, phone_guestbook.cpp]
2023-08-07 Correction enchainement livre d'or
    [Livre_dor.ino, phone_guestbook.cpp]
2023-08-20 Gestion bouton changement de mode inversé
2023-09-10 Gestion des numéros multiples
2023-09-27 Correction fonctionnement boite a histoires
    [Boite_a_histoires_S63.ino, RotaryDialer.cpp, Variables.h]
2023-09-30 Correction circuit
    [Schema_Seeduino_Xiao.fz]
2023-10-01 Correction rendu visuel schéma
    [Schema_Seeduino_Xiao.fz]
2023-10-10 Ajout stethoscope
    [PN532.fzz]
2023-10-10 Stockage des tags dans une liste
2023-11-22 Premier jet tentative de gestion du volume des boites à histoires
2023-11-23 Ajout de la gestion du volume
2023-12-08 Réorganisation du dépot
    [AudioGuestbook.fzz, Schema.fzz, Schema_Arduino_Nano.fz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]
2024-05-31 Intégration de Bounce
2024-08-19 Corrections et ajout options
    [Boite_a_histoires.ino, DFRobotDFPlayerMini.cpp, DFRobotDFPlayerMini.h]
2024-12-29 Corrections sur calcul numero compose
    [Boite_a_histoires.ino, Variables.h]
2025-09-29 Corrections fonctionnement livre d'or
    [Livre_dor.ino, Settings.h, phone_guestbook.h]
2025-12-05 Ajout de références
2026-04-24 Ajout fonctionnalité de random

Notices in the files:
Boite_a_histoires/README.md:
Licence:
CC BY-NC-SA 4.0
